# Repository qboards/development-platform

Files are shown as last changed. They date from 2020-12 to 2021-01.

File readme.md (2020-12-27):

# Modular Development Board

This board is essentially a breakout board for power, communication
and IO ports to a microcontroller or other suitable device. Multiple 
minimal microcontroller boards can be connected and easily swapped out
to have a full featured development board, that is not permanently tied
to a single microcontroller.

> TODO: list of modules

## Dev board Connector

> TODO

### Pinout

| Pin number | Function | | Pin number | Function  | | Pin number | Function | | Pin number | Function |
|---|---|---|---|---|---|---|---|---|---|---|
| 1 | GND | | 21 | PORTA_6 | | 41 | PORTB_8  | | 61 | PORTD_2  |
| 2 | GND | | 22 | COMM_TX_2 | | 42 | ICSP4 | | 62 | PORTE_8  |
| 3 | VBUS | | 23 | PORTA_7 | | 43 | PORTC_1  | | 63 | PORTD_3  |
| 4 | VBUS | | 24 | COMM_RX_2 | | 44 | ICSP5 | | 64 | PORTE_7  |
| 5 | 5v | | 25 | PORTA_8 | | 45 | PORTC_2  | | 65 | PORTD_4  |
| 6 | 5v | | 26 | COMM_TX_3 | | 46 | ICSP6 | | 66 | PORTE_6  |
| 7 | 3v3 | | 27 | PORTB_1 | | 47 | PORTC_3  | | 67 | PORTD_5  |
| 8 | 3v3 | | 28 | COMM_RX_3 | | 48 | ICSP7 | | 68 | PORTE_5  |
| 9 | 1v8 | | 29 | PORTB_2 | | 49 | PORTC_4  | | 69 | PORTD_6  |
| 10 | 1v8 | | 30 | COMM_TX_4 | | 50 | ICSP8 | | 70 | PORTE_4  |
| 11 | PORTA_1 | | 31 | PORTB_3 | | 51 | PORTC_5  | | 71 | PORTD_7  |
| 12 | COMM_RTS_1 | | 32 | COMM_RX_4 | | 52 | ICSP9 | | 72 | PORTE_3  |
| 13 | PORTA_2 | | 33 | PORTB_4 | | 53 | PORTC_6  | | 73 | PORTD_8  |
| 14 | COMM_CTS_1 | | 34 | NC | | 54 | ICSP10 | | 74 | PORTE_2  |
| 15 | PORTA_3 | | 35 | PORTB_5 | | 55 | PORTC_7  | | 75 | NC |
| 16 | COMM_DTR_1 | | 36 | ICSP1 | | 56 | NC | | 76 | PORTE_1  |
| 17 | PORTA_4 | | 37 | PORTB_6 | | 57 | PORTC_8  | | 77 | VBUS |
| 18 | COMM_TX_1  | | 38 | ICSP2 | | 58 | RST_A | | 78 | VBUS |
| 19 | PORTA_5 | | 39 | PORTB_7 | | 59 | PORTD_1  | | 79 | GND |
| 20 | COMM_RX_1  | | 40 | ICSP3 | | 60 | RST_B | | 80 | GND |

## Power supply

Input power can be delivered through the external power (barrel jack or 
screw terminals) or the USB connector. Selecting power from either the 
external inputs or the USB connector can be done with the **Power source** 
jumper.

Input on the external power terminals should be in the range
of 6 up to 15 volt. The polarity on the external input does not matter,
the development board will correct the polarity.

> TODO: Add current requirements.

The input power is regulated to 5V, 3.3V and 1.8V rails, which are 
all supplied to the development module. The module itself can pick one
of those rails and feed that rail back as VCC. For all rails and the 
ground rail test points are supplied.

> TODO: Add description of protection

## Communication

There are four serial ports that modules can expose, one fully featured (TX, RX, 
DTR, CTS, RTS) and three basic (TX, RX only). The development board has a single
USB to serial UART interface (FTDI FT232RL) connected to the USB input and the
other end can be connected with the jumper interfaces to any of the four serial
connections to the development module.

> TODO: Add image of communication jumpers

There are two LED indicators for TX and RX activity.

## Port modules

> TODO

## In Circuit Programming (ICP)

| ICP Pin | AVR Function |
|---|---|
| 1 | MOSI |
| 2 | VCC (VBUS) |
| 3 | Unused (NC)  |
| 4 | GND |
| 5 | RESET |
| 6 | GND |
| 7 | SCK |
| 8 | GND |
| 9 | MISO |
| 10 | GND |

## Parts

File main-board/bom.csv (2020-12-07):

Ref | Qnty | Value | Manufacturer | Manufacturer part nr | Package | Part | Farnell #
C1 | 1 | 100uF | MULTICOMP PRO | MCVKZ010M101FB3L | 6.3x5.7 | Polarized SMD capacitor | 2611328
C2 | 1 | 1000uF | MULTICOMP PRO | MCVVT6R3M102FB3L | 8x5.7 | Polarized SMD capacitor | 2611416
C3, C4 | 2 | 22uF | MULTICOMP PRO | MCVVT063M220FB3L | 6.3x5.7 | Polarized SMD capacitor | 2611407
C5 | 1 | 10uF |  |  | 0805 | Unpolarized SMD capacitor
C6, C7 | 2 | 100nF |  |  | 0805 | Unpolarized SMD capacitor
D1, D2, D3, D4 | 4 | 1N4007 |  |  | SMA | Diode, small symbol
D5 | 1 |  | DIODES INC. | ZLLS400TA | 0805 | Small Signal Schottky Diode | 3127494
D6, D7, D8, D9, D10, D11, D12, D13, D14, D15, D16, D17, D18, D19, D20, D21, D22, D23, D24, D25, D26, D27, D28, D29, D30, D31, D32, D33, D34, D35, D36, D37, RX1, TX1 | 34 |  | KINGBRIGHT | KP-2012LSGC | 0805 | Low power SMD LED | 2463991
D38 | 1 |  | KINGBRIGHT | KP-2012LSGC | 0805 | Low power SMD LED | 2463991
F1 | 1 | 500mA | BOURNS | MF-PSMF050X-2 | 0805 | Resettable fuse, polymeric positive temperature coefficient | 1294876
J1 | 1 |  |  |  |  | Pin header, 2.54mm, 1 row, 3 contacts
J2 | 1 |  |  |  |  | Pin header, 2.54mm, 1 row, 6 contacts
J3 | 1 |  |  |  |  | Pin header, 2.54mm, 2 rows, 10 contacts
J4 | 1 |  |  |  |  | Pin header, 2.54mm, 2 rows, 6 contacts
J5 | 1 |  |  |  |  | Pin header, 2.54mm, 1 row, 3 contacts
J7, J8, J9, J10, J11, J12, J13, J14, J15 | 9 |  |  |  |  | Pin header, 2.54mm, 2 rows, 10 contacts
J16 | 1 |  |  |  |  | Pin header, 2.54mm, 1 row, 3 contacts
J17 | 1 |  | KITRONIK | 5601B |  | Edge Connector (BBC micro:bit compatible) | 2563845
J18 | 1 |  | CLIFF ELECTRONIC COMPONENTS | FC68148 |  | DC Barrel Jack Power Connector, 2.1mm | 224959
J19 | 1 |  |  |  |  | Screw terminal, 1 row, 2 contacts
J20 | 1 |  |  |  |  | Pin header, 2.54mm, 1 row, 3 contacts
J21 | 1 |  |  |  |  | Pin header, 2.54mm, 1 row, 6 contacts
L1 | 1 | 100uH | WURTH ELEKTRONIK | 74404086101 |  | Power Inductor (SMD) | 2842174
R2, R6, R7 | 3 | 1K |  |  | 0805 | SMD resistor
R3, R4, R5 | 3 | 10K |  |  | 0805 | SMD resistor
R8, R9 | 2 |  |  |  | 0805 | SMD resistor
R10, R11, R12, R13, R14, R15, R16, R17, R18, R19, R20, R21, R22, R23, R24, R25, R26, R27, R28, R29, R30, R31, R32, R33, R34, R35, R36, R37, R38, R39, R40, R41 | 32 | 10k |  |  | 0805 | SMD resistor
SW1 | 1 |  | SCHURTER | 1301.9303 |  | Through hole tactile switch, 6mm | 1217774
SW2 | 1 |  | ALCOSWITCH - TE CONNECTIVITY | TDS04SGNNTU04 |  | DIP / SIP Switch, Raised Type, 4 Circuits, SP3T | 2792778
SW3 | 1 |  | ALCOSWITCH - TE CONNECTIVITY | EDS04SGNNTU04Q |  | DIP / SIP Switch, Raised Type, 4 Circuits, SPST | 2792676
SW4, SW5, SW6, SW7, SW8, SW9, SW10, SW11, SW13, SW14, SW15, SW16, SW17, SW18, SW19, SW20, SW22, SW23, SW24, SW25, SW26, SW27, SW28, SW29, SW31, SW32, SW33, SW34, SW35, SW36, SW37, SW38 | 32 |  | SCHURTER | 1301.9303 |  | Through hole tactile switch, 6mm | 1217774
SW12, SW21, SW30, SW39 | 4 |  | ALCOSWITCH - TE CONNECTIVITY | TDS08SGNNTU04 |  | DIP / SIP Switch, Raised Type, 8 Circuits, SP3T | 2792779
SW41 | 1 |  | C & K COMPONENTS | OS102011MA1QN1 |  | Slide Switch, SPDT, On-On, Through Hole | 1201431
U1 | 1 |  | TEXAS INSTRUMENTS | LM2576HVS-5.0/NOPB | TO-263-5 | Buck (Step Down) Switching Regulator, Fixed, 4V-60V In, 5V And 3A Out, 52 kHz | 2382943
U2 | 1 | AP1117-33 | DIODES INC. | AP1117E33G-13 | SOT-223-3 | 1A Low Dropout regulator, positive, 3.3V fixed output, SOT-223 | 1825291
U3 | 1 | AP1117-18 | DIODES INC. | AP1117E18G-13 | SOT-223-3 | 1A Low Dropout regulator, positive, 1.8V fixed output, SOT-223 | 1825289
U4 | 1 | FT232RL | FTDI | FT232RL | SSOP-28 | USB to Serial Interface, SSOP-28 | 1146032
USB_1 | 1 |  |  |  |  | USB Type B connector

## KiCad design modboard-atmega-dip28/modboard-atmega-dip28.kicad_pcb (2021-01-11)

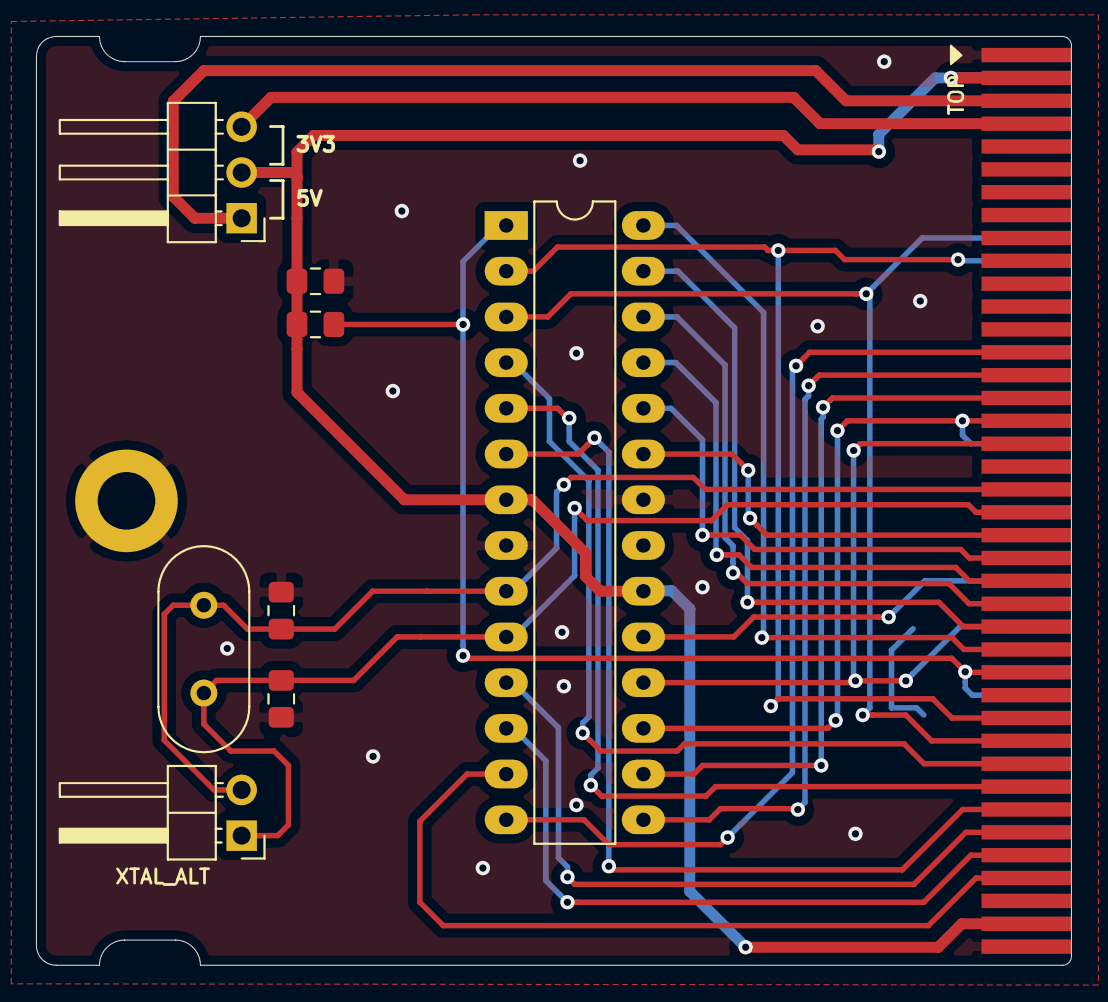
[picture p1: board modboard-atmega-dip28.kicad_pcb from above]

Board: 2 copper layers, 57.5 x 51.6 mm, 11 parts (1 on the bottom side), 27 nets.

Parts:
ATmega-DIP28: LOGO_BRD_REF; logo_url-5mm
C1, C2, C3: C; C_0805_2012Metric_Pad1.15x1.40mm_HandSolder
H1: MountingHole_Pad; MountingHole_3.2mm_M3_ISO7380_Pad
J1: modboard-edge-connector; modboard_edge_connector
J2: Conn_01x03_Male; PinHeader_1x03_P2.54mm_Horizontal
R1: 10K; R_0805_2012Metric_Pad1.15x1.40mm_HandSolder
U1: ATMEGA328P-PU; DIP-28_W7.62mm_LongPads
XTAL_ALT: Conn_01x02_Male; PinHeader_1x02_P2.54mm_Horizontal
Y1: Crystal; Crystal_HC49-4H_Vertical

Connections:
GND: C1.2, C2.2, C3.2, H1.1, J1.1, J1.2, J1.42, J1.46, J1.50, J1.54, J1.60, J1.79, J1.80, U1.8, U1.22
MISO: J1.35, J1.52, U1.18
MOSI: J1.33, J1.36, U1.17
unnamed: C2.1, J1.39, U1.9, XTAL_ALT.2, Y1.1
unnamed: C3.1, J1.41, U1.10, XTAL_ALT.1, Y1.2
unnamed: J1.5, J1.6, J2.1
unnamed: J1.7, J1.8, J2.3
unnamed: J1.27, U1.14
unnamed: J1.29, U1.15
unnamed: J1.31, U1.16
unnamed: J1.43, U1.23
unnamed: J1.45, U1.24
unnamed: J1.47, U1.25
unnamed: J1.49, U1.26
unnamed: J1.51, U1.27
unnamed: J1.53, U1.28
unnamed: J1.63, U1.4
unnamed: J1.65, U1.5
unnamed: J1.67, U1.6
unnamed: J1.69, U1.11
unnamed: J1.71, U1.12
unnamed: J1.73, U1.13
RESET: J1.44, J1.55, J1.58, R1.2, U1.1
RX: J1.20, J1.59, U1.2
SCK: J1.37, J1.48, U1.19
TX: J1.18, J1.61, U1.3
VCC: C1.1, J1.3, J1.4, J1.77, J1.78, J2.2, R1.1, U1.7, U1.20

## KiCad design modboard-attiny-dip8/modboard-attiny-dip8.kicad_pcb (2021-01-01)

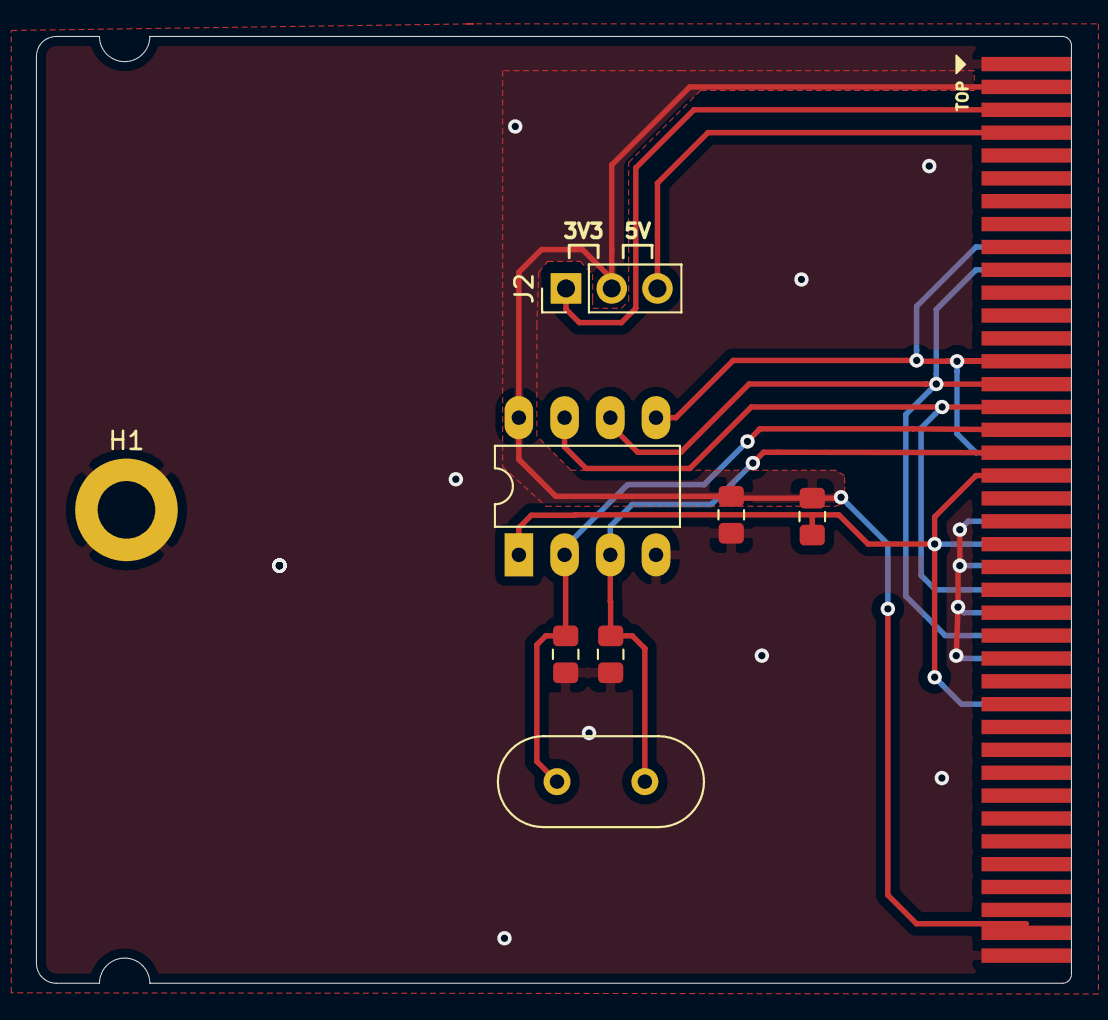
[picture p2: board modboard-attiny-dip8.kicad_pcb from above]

Board: 2 copper layers, 57.5 x 52.6 mm, 10 parts (1 on the bottom side), 10 nets.

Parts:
ATTINY-DIP8: LOGO_BRD_REF; logo_url-5mm
C1, C2, C3: C; C_0805_2012Metric_Pad1.15x1.40mm_HandSolder
H1: MountingHole_Pad; MountingHole_3.2mm_M3_ISO7380_Pad
J1: modboard-edge-connector; modboard_edge_connector
J2: Conn_01x03_Male; PinHeader_1x03_P2.54mm_Vertical
R1: 10K; R_0805_2012Metric_Pad1.15x1.40mm_HandSolder
U1: ATTINY85-20PU; DIP-8_W7.62mm_LongPads
Y1: Crystal; Crystal_HC49-4H_Vertical

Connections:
GND: C1.2, C2.2, C3.2, H1.1, J1.1, J1.2, J1.42, J1.46, J1.50, J1.54, J1.60, J1.79, J1.80, U1.4
MISO: J1.20, J1.29, J1.52, U1.6
MOSI: J1.18, J1.27, J1.36, U1.5
unnamed: C2.1, J1.35, U1.3, Y1.1
unnamed: C3.1, J1.33, U1.2, Y1.2
unnamed: J1.5, J1.6, J2.1
unnamed: J1.7, J1.8, J2.3
RESET: J1.37, J1.44, J1.58, R1.2, U1.1
SCK: J1.31, J1.48, U1.7
VCC: C1.1, J1.3, J1.4, J1.77, J1.78, J2.2, R1.1, U1.8

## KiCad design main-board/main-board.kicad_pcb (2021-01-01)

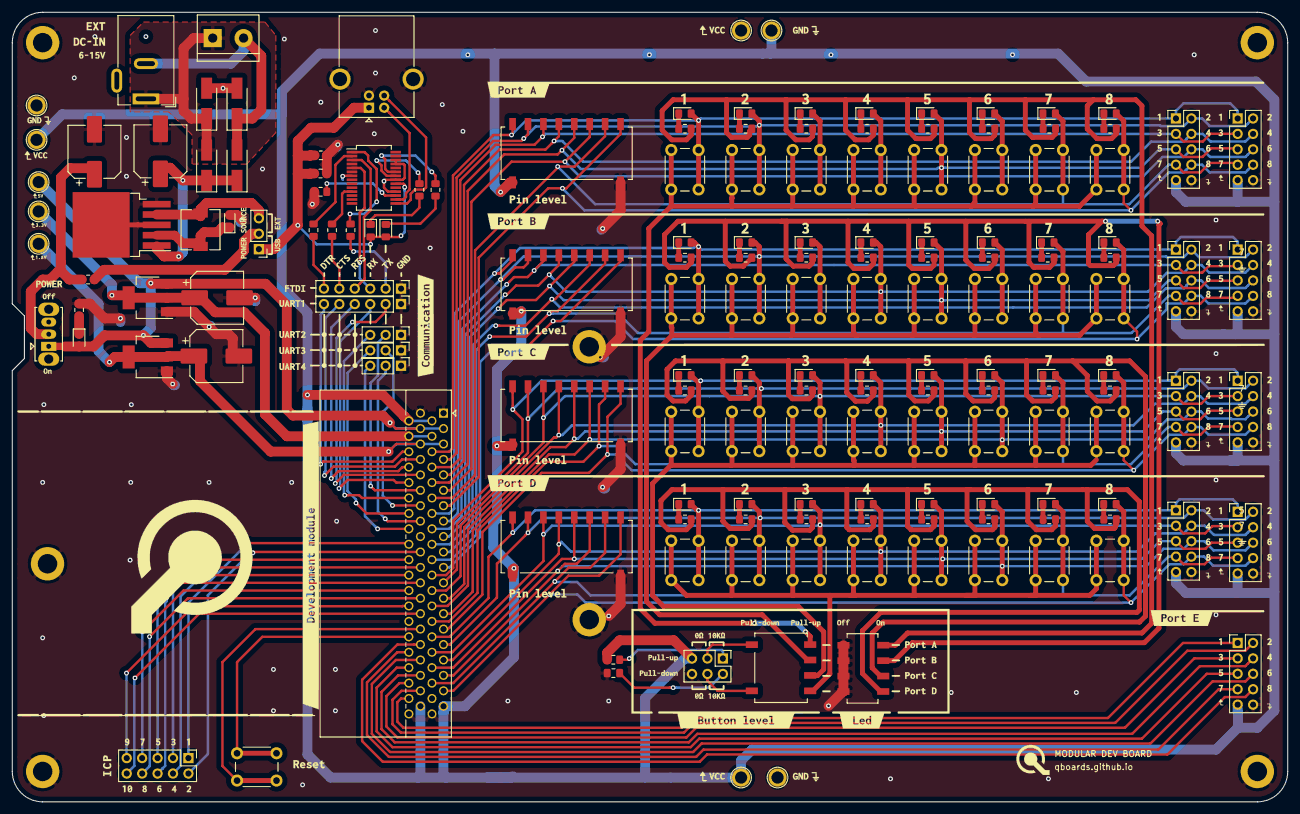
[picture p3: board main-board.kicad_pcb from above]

Board: 2 copper layers, 210.0 x 130.0 mm, 173 parts (1 on the bottom side), 136 nets.

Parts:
C1: 100uF; CP_Elec_8x10.5
C2: 1000uF; CP_Elec_8x10.5
C3, C4: 22uF; CP_Elec_8x10.5
C5: 10uF; C_0805_2012Metric_Pad1.15x1.40mm_HandSolder
C6, C7: 100nF; C_0805_2012Metric_Pad1.15x1.40mm_HandSolder
D1, D2, D3, D4: 1N4007; D_SMA_Handsoldering
D5: D_Schottky_Small; D_SOD-323_HandSoldering
D6, D7, D8, D9, D10, D11, D12, D13, D14, D15, D16, D17, D18, D19, D20, D21, D22, D23, D24, D25, D26, D27, D28, D29, D30, D31, D32, D33, D34, D35, D36, D37: LED_Small; LED_0805_2012Metric_Pad1.15x1.40mm_HandSolder
D38: PWR_EN; LED_0805_2012Metric_Pad1.15x1.40mm_HandSolder
F1: 500mA; Fuse_0805_2012Metric_Pad1.15x1.40mm_HandSolder
H1, H2, H3, H4, H5, H6, H7: MountingHole_Pad; MountingHole_3.2mm_M3_ISO14580_Pad
J1: PWR_SELECT; PinHeader_1x03_P2.54mm_Vertical
J2: COMM1; PinHeader_1x06_P2.54mm_Vertical
J3: ICSP; PinHeader_2x05_P2.54mm_Vertical
J4: Conn_02x03_Top_Bottom; PinHeader_2x03_P2.54mm_Vertical
J5: COMM_2; PinHeader_1x03_P2.54mm_Vertical
J7, J8, J9, J10, J11, J12, J13, J14, J15: Conn_02x05_Odd_Even; PinHeader_2x05_P2.54mm_Vertical
J16: COMM_3; PinHeader_1x03_P2.54mm_Vertical
J17: Modular board connector; 4UCON_10156_2x40_P1.27mm_Socket_Horizontal
J18: PWR_EXT_1; BarrelJack_Wuerth_6941xx301002
J19: PWR_EXT_2; TerminalBlock_bornier-2_P5.08mm
J20: COMM_4; PinHeader_1x03_P2.54mm_Vertical
J21: COMM_OUT; PinHeader_1x06_P2.54mm_Vertical
L1: 100uH; L_6.3x6.3_H3
MODULAR DEV BOARD: LOGO_BRD_REF; logo_url-5mm
MODULAR DEV BOARD | Rev 1.0: LOGO_BRD_REF; logo_url-5mm
R2, R6, R7: 1K; R_0805_2012Metric_Pad1.15x1.40mm_HandSolder
R3, R4, R5: 10; R_0805_2012Metric_Pad1.15x1.40mm_HandSolder
R8, R9: R_Small; R_0805_2012Metric_Pad1.15x1.40mm_HandSolder
R10, R11, R12, R13, R14, R15, R16, R17, R18, R19, R20, R21, R22, R23, R24, R25, R26, R27, R28, R29, R30, R31, R32, R33, R34, R35, R36, R37, R38, R39, R40, R41: 10k; R_0805_2012Metric_Pad1.15x1.40mm_HandSolder
RX1: LED_Small; LED_0805_2012Metric_Pad1.15x1.40mm_HandSolder
SW1: RESET; SW_PUSH_6mm
SW2: BTN_LEVEL; TE_TDS04SG
SW3: LED_GND; TE_EDS04SG
SW4, SW5, SW6, SW7, SW8, SW9, SW10, SW11, SW13, SW14, SW15, SW16, SW17, SW18, SW19, SW20, SW22, SW23, SW24, SW25, SW26, SW27, SW28, SW29, SW31, SW32, SW33, SW34, SW35, SW36, SW37, SW38: SW_Push; SW_PUSH_6mm
SW12, SW21, SW30, SW39: SW_SP3T_x08; TE_TDS08SG
SW41: PWR_EN; SW_Slide_1P2T_CK_OS102011MS2Q
TP_1V1: 1V8; TestPoint_Plated_Hole_D2.0mm
TP_3V3: 3V3; TestPoint_Plated_Hole_D2.0mm
TP_5V1: 5V; TestPoint_Plated_Hole_D2.0mm
TP_GND1, TP_GND2, TP_GND3: GND; TestPoint_Plated_Hole_D2.0mm
TP_VBUS1, TP_VBUS2, TP_VBUS3: VBUS; TestPoint_Plated_Hole_D2.0mm
TX1: LED_Small; LED_0805_2012Metric_Pad1.15x1.40mm_HandSolder
U1: LM2576HVS-5; TO-263-5_TabPin3
U2: AP1117-33; SOT-223-3_TabPin2
U3: AP1117-18; SOT-223-3_TabPin2
U4: FT232RL; SSOP-28_5.3x10.2mm_P0.65mm
USB_1: USB_B; USB_B_OST_USB-B1HSxx_Horizontal
[BRD_REF]: LOGO_BRD_REF; logo-20mm

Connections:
+1V8: C4.1, J17.9, J17.10, TP_1V1.1, U3.2
+3V3: C3.1, J17.7, J17.8, TP_3V3.1, U2.2
+5V: D38.2, J17.5, J17.6, SW41.1, TP_5V1.1, U2.3, U3.3
/PORT_A_BTN_LEVEL: SW2.1, SW4.2, SW5.2, SW6.2, SW7.2, SW8.2, SW9.2, SW10.2, SW11.2
/PORT_A_LED_GND: R10.1, R11.1, R12.1, R13.1, R14.1, R15.1, R16.1, R17.1, SW3.2
/PORT_A_PIN1: D6.2, J7.1, J8.1, J17.11, SW4.1, SW12.1
/PORT_A_PIN2: D7.2, J7.2, J8.2, J17.13, SW5.1, SW12.2
/PORT_A_PIN3: D8.2, J7.3, J8.3, J17.15, SW6.1, SW12.3
/PORT_A_PIN4: D9.2, J7.4, J8.4, J17.17, SW7.1, SW12.4
/PORT_A_PIN5: D10.2, J7.5, J8.5, J17.19, SW8.1, SW12.5
/PORT_A_PIN6: D11.2, J7.6, J8.6, J17.21, SW9.1, SW12.6
/PORT_A_PIN7: D12.2, J7.7, J8.7, J17.23, SW10.1, SW12.7
/PORT_A_PIN8: D13.2, J7.8, J8.8, J17.25, SW11.1, SW12.8
/PORT_B_BTN_LEVEL: SW2.2, SW13.2, SW14.2, SW15.2, SW16.2, SW17.2, SW18.2, SW19.2, SW20.2
/PORT_B_LED_GND: R18.1, R19.1, R20.1, R21.1, R22.1, R23.1, R24.1, R25.1, SW3.4
/PORT_B_PIN1: D14.2, J9.1, J10.1, J17.27, SW13.1, SW21.1
/PORT_B_PIN2: D15.2, J9.2, J10.2, J17.29, SW14.1, SW21.2
/PORT_B_PIN3: D16.2, J9.3, J10.3, J17.31, SW15.1, SW21.3
/PORT_B_PIN4: D17.2, J9.4, J10.4, J17.33, SW16.1, SW21.4
/PORT_B_PIN5: D18.2, J9.5, J10.5, J17.35, SW17.1, SW21.5
/PORT_B_PIN6: D19.2, J9.6, J10.6, J17.37, SW18.1, SW21.6
/PORT_B_PIN7: D20.2, J9.7, J10.7, J17.39, SW19.1, SW21.7
/PORT_B_PIN8: D21.2, J9.8, J10.8, J17.41, SW20.1, SW21.8
/PORT_C_BTN_LEVEL: SW2.3, SW22.2, SW23.2, SW24.2, SW25.2, SW26.2, SW27.2, SW28.2, SW29.2
/PORT_C_LED_GND: R26.1, R27.1, R28.1, R29.1, R30.1, R31.1, R32.1, R33.1, SW3.6
/PORT_C_PIN1: D22.2, J11.1, J12.1, J17.43, SW22.1, SW30.1
/PORT_C_PIN2: D23.2, J11.2, J12.2, J17.45, SW23.1, SW30.2
/PORT_C_PIN3: D24.2, J11.3, J12.3, J17.47, SW24.1, SW30.3
/PORT_C_PIN4: D25.2, J11.4, J12.4, J17.49, SW25.1, SW30.4
/PORT_C_PIN5: D26.2, J11.5, J12.5, J17.51, SW26.1, SW30.5
/PORT_C_PIN6: D27.2, J11.6, J12.6, J17.53, SW27.1, SW30.6
/PORT_C_PIN7: D28.2, J11.7, J12.7, J17.55, SW28.1, SW30.7
/PORT_C_PIN8: D29.2, J11.8, J12.8, J17.57, SW29.1, SW30.8
/PORT_D_BTN_LEVEL: SW2.4, SW31.2, SW32.2, SW33.2, SW34.2, SW35.2, SW36.2, SW37.2, SW38.2
/PORT_D_LED_GND: R34.1, R35.1, R36.1, R37.1, R38.1, R39.1, R40.1, R41.1, SW3.8
/PORT_D_PIN1: D30.2, J13.1, J14.1, J17.59, SW31.1, SW39.1
/PORT_D_PIN2: D31.2, J13.2, J14.2, J17.61, SW32.1, SW39.2
/PORT_D_PIN3: D32.2, J13.3, J14.3, J17.63, SW33.1, SW39.3
/PORT_D_PIN4: D33.2, J13.4, J14.4, J17.65, SW34.1, SW39.4
/PORT_D_PIN5: D34.2, J13.5, J14.5, J17.67, SW35.1, SW39.5
/PORT_D_PIN6: D35.2, J13.6, J14.6, J17.69, SW36.1, SW39.6
/PORT_D_PIN7: D36.2, J13.7, J14.7, J17.71, SW37.1, SW39.7
/PORT_D_PIN8: D37.2, J13.8, J14.8, J17.73, SW38.1, SW39.8
/PORT_E_PIN1: J15.1, J17.76
/PORT_E_PIN2: J15.2, J17.74
/PORT_E_PIN3: J15.3, J17.72
/PORT_E_PIN4: J15.4, J17.70
/PORT_E_PIN5: J15.5, J17.68
/PORT_E_PIN6: J15.6, J17.66
/PORT_E_PIN7: J15.7, J17.64
/PORT_E_PIN8: J15.8, J17.62
GND: C1.2, C2.2, C3.2, C4.2, C5.1, C6.1, C7.2, D1.2, D3.2, D5.2, H1.1, H2.1, H3.1, H4.1, H5.1, H6.1, H7.1, J2.1, J4.6, J5.1, J7.10, J8.10, J9.10, J10.10, J11.10, J12.10, J13.10, J14.10, J15.10, J16.1, J17.1, J17.2, J17.79, J17.80, J20.1, J21.1, R2.2, R9.1, SW3.1, SW3.3, SW3.5, SW3.7, SW12.-, SW21.-, SW30.-, SW39.-, TP_GND1.1, TP_GND2.1, TP_GND3.1, U1.3, U1.5, U2.1, U3.1, U4.7, U4.18, U4.21, U4.25, U4.26, USB_1.4, USB_1.5
ICSP1: J3.1, J17.36
ICSP2: J3.2, J17.38
ICSP3: J3.3, J17.40
ICSP4: J3.4, J17.42
ICSP5: J3.5, J17.44
ICSP6: J3.6, J17.46
ICSP7: J3.7, J17.48
ICSP8: J3.8, J17.50
ICSP9: J3.9, J17.52
ICSP10: J3.10, J17.54
unnamed: C1.1, D2.1, D4.1, U1.1
unnamed: C2.1, F1.1, SW41.2
unnamed: C5.2, C6.2, J1.1, RX1.2, TX1.2, U4.20, USB_1.1
unnamed: C7.1, U4.17
unnamed: D1.1, D2.2, J18.1, J19.1
unnamed: D3.1, D4.2, J18.2, J19.2
unnamed: D5.1, L1.1, U1.2
unnamed: D6.1, R10.2
unnamed: D7.1, R11.2
unnamed: D8.1, R12.2
unnamed: D9.1, R13.2
unnamed: D10.1, R14.2
unnamed: D11.1, R15.2
unnamed: D12.1, R16.2
unnamed: D13.1, R17.2
unnamed: D14.1, R18.2
unnamed: D15.1, R19.2
unnamed: D16.1, R20.2
unnamed: D17.1, R21.2
unnamed: D18.1, R22.2
unnamed: D19.1, R23.2
unnamed: D20.1, R24.2
unnamed: D21.1, R25.2
unnamed: D22.1, R26.2
unnamed: D23.1, R27.2
unnamed: D24.1, R28.2
unnamed: D25.1, R29.2
unnamed: D26.1, R30.2
unnamed: D27.1, R31.2
unnamed: D28.1, R32.2
unnamed: D29.1, R33.2
unnamed: D30.1, R34.2
unnamed: D31.1, R35.2
unnamed: D32.1, R36.2
unnamed: D33.1, R37.2
unnamed: D34.1, R38.2
unnamed: D35.1, R39.2
unnamed: D36.1, R40.2
unnamed: D37.1, R41.2
unnamed: D38.1, R2.1
unnamed: F1.2, J1.2
unnamed: J1.3, L1.2, U1.4
unnamed: J4.1, R8.1
unnamed: J4.2, R9.2
unnamed: J4.3, SW2.+
unnamed: J4.4, SW2.-
unnamed: J16.2, J17.26
unnamed: J16.3, J17.28
unnamed: J2.6, J17.12
unnamed: J2.5, J17.14
unnamed: J2.4, J17.16
unnamed: J2.2, J17.18
unnamed: J2.3, J17.20
unnamed: J5.2, J17.22
unnamed: J5.3, J17.24
unnamed: J17.30, J20.2
unnamed: J17.32, J20.3
unnamed: J17.58, SW1.2
unnamed: J17.60, SW1.1
unnamed: J21.2, R3.2
unnamed: J21.3, U4.5
unnamed: J21.4, U4.3
unnamed: J21.5, R4.2
unnamed: J21.6, R5.2
unnamed: R3.1, U4.1
unnamed: R4.1, U4.11
unnamed: R5.1, U4.2
unnamed: R6.1, TX1.1
unnamed: R6.2, U4.23
unnamed: R7.1, U4.22
unnamed: R7.2, RX1.1
unnamed: U4.15, USB_1.3
unnamed: U4.16, USB_1.2
VBUS: J4.5, J7.9, J8.9, J9.9, J10.9, J11.9, J12.9, J13.9, J14.9, J15.9, J17.3, J17.4, J17.77, J17.78, R8.2, SW12.+, SW21.+, SW30.+, SW39.+, TP_VBUS1.1, TP_VBUS2.1, TP_VBUS3.1

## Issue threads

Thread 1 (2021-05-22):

SW3 inconstent style with other switches

wilcotomassen, 2021-05-22:
SW3 footprint is for the J-style footprint (leads folded under the package), using the gullwing style (m-series) is more consistent with the other switches.

Current footprint component: [EDS04SNNNTU04Q](https://nl.farnell.com/alcoswitch-te-connectivity/eds04snnntu04q/dip-switch-4pos-spst-slide-smd/dp/2792682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)
Gullwing component: [EDS04SGNNTU04Q](https://nl.farnell.com/alcoswitch-te-connectivity/eds04sgnntu04q/dip-switch-4pos-spst-slide-smd/dp/2792676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)

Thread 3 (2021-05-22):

Current component for L1 in bom is not correct for the footprint

wilcotomassen, 2021-05-22:
Current component for L1 in bom is not correct for the footprint

Footprint: 6.3x6.3mm SMD
[Component](https://nl.farnell.com/wurth-elektronik/74404086101/inductor-100uh-1-35a-20-semi-shld/dp/2842174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): 8.0x8.0mm SMD

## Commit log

2020-05-08 Added inital readme with power supply requirements and thoughts
2020-05-17 Initial iteration
    [main-board.kicad_pcb, main-board.sch]
2020-06-27 First layout
    [file5EC3520F.sch, main-board.kicad_pcb, main-board.sch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]
2020-06-27 Changed button pullup-down selector
    [main-board.kicad_pcb, main-board.sch]
2020-06-27 Rotated isp connector
    [main-board.kicad_pcb]
2020-06-27 Added filled zones
    [main-board.kicad_pcb]
2020-06-27 Added module board hole
    [main-board.kicad_pcb, main-board.sch]
2020-10-18 Updated footprints
    [main-board.kicad_pcb, main-board.sch]
2020-11-29 Updated silkscreens
    [main-board.kicad_pcb]
2020-11-30 Cleaned up Dwgs.User
    [main-board.kicad_pcb]
2020-11-30 Added QBoard logos
    [main-board.kicad_pcb]
2020-11-30 Added sheet metadata
    [file5EC3520F.sch, main-board.sch, port-breakout.sch]
2020-12-07 Added bom
    [bom.csv]
2020-12-07 Initial ATTiny DIP8 board
    [modboard-attiny-dip8.kicad_pcb, modboard-attiny-dip8.sch]
2020-12-27 Updated connector and board size
    [modboard-attiny-dip8.kicad_pcb]
2020-12-27 Added ICP connections, labeled VBUS header
    [modboard-attiny-dip8.kicad_pcb, modboard-attiny-dip8.sch]
2020-12-27 Added mounting hole, fixed routing
    [modboard-attiny-dip8.kicad_pcb, modboard-attiny-dip8.sch]
2021-01-01 Added logo
    [modboard-atmega-dip28.kicad_pcb]
2021-01-01 Fixed GND plane
    [modboard-atmega-dip28.kicad_pcb]
2021-01-01 Added rev number, added sheet data
    [modboard-atmega-dip28.kicad_pcb]
2021-01-01 Fixed revision number
    [main-board.kicad_pcb]
2021-01-11 Updated board size, connector and reference text
    [modboard-atmega-dip28.kicad_pcb]
2021-01-23 Added silkscreen image source
